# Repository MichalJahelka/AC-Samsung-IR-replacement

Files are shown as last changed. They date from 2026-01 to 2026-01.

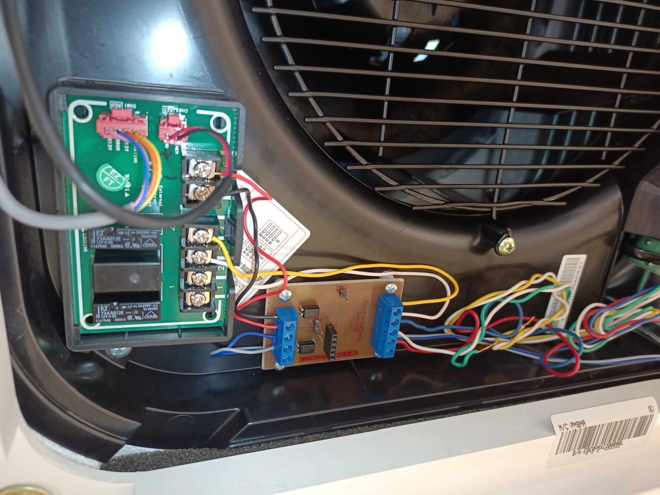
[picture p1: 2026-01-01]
Doc/Mount.jpg

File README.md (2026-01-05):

Wire replacement for SAMCUNG AC Remote Controller AR-EC03E/EH03E/EC03M/EH03M
IR protocol decoding, creating end sending example
IR protocol enconding for smart house realization

No protocol found for Samsung air condition IR control, so I had to catch communication with IR receiver (38 kHz) and decode it with MCU. I did not gues all bits, but the biggest part of protocol was decoded. For decoding is used PIC18F47K40, sends data throug serial line to terminal for display at PC. Program IRprotokolSamsungAC.X is written in MPLAB X, uses free compiler, has CZECH comments (so translator can be handy).
IRprotokolSamsungAC.X can decode protocols and after uncomment
//TransmittPacket(Paket,Delka);
//while(1);
can emulate one time data sending.
I tested it with IR LED, so pin with 38 kHz modulation is there too.

At second part KlimatizaceSamsung.X is practical usage. It uses iDum protocol for communication with control unit, data are passed to CreatePaket function and then created packet is send to output. It does not using IR LED, it connects throug optocoupler to IR receiver at AC unit, so modulation is not needed. Practilal realisation has schematic and PCB.

There is no problem to use it in another own device. Important is creating packet and sending it:
When data arrives:
if(Zprava.Data.Obsah.ZArray.Data[0]==rksCommand)
{
  Opt=(TOptions *)&Zprava.Data.Obsah.ZArray.Data[4];
  Swing=(TSwing *)&Zprava.Data.Obsah.ZArray.Data[6];
  i=CreatePaket(SamsungPaket,Zprava.Data.Obsah.ZArray.Data[1],    // Mode
                             Zprava.Data.Obsah.ZArray.Data[2],    // Temperature
                             Zprava.Data.Obsah.ZArray.Data[3],    // Fan
                             *Opt,                                // Options
                             *Swing,                              // Swing
                             Zprava.Data.Obsah.ZArray.Data[7],    // Zone
                             Zprava.Data.Obsah.ZArray.Data[8]);   // Direction
  VysliAccept();
  TransmittPacket(SamsungPaket,i);
  break;
}

And sending is automatic with TMR5 interrupt:
PIE4=0b00010011;      // TMR5IE,TMR2IE,TMR1IE
IPR4=0b00010001;      // TMR5 (Samsung transmitt), TMR1 (iDum) High priority

void __interrupt() Preruseni(void)
{
  iDumProcessIntr();
  TransmittBlockInterrupt(); // here is sending realized
}

CreatePaket, TransmittPacket and TransmittBlockInterrupt functions are parts of SamsungIR library.

Schematic is in KiCAD, extended documents are in CZECH language, use transaltor if you want.

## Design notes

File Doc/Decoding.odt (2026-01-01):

HDR0 CHK1 DI Q HDR1 ZoneCHK2 P SWING TUOL C YC Temp Fan+Mode RB pp

01000000 01001001 11110000 00000000 00000000 00000000 00001111 10000000 01000111 01111111 10001110 00000001 10000010 00001111 nic
01000000 01001001 11110000 00000000 00000000 00000000 00001111 10000000 01000011 01111111 11101110 00000001 10000010 00001111 turbo
01000000 01000001 11110000 00000000 00000000 00000100 00001111 10000000 01000111 01111111 10001110 00000001 10000010 00001111 quiet
01000000 01001001 11110000 00000000 00000000 00000000 00001111 10000000 01001011 01111111 10001110 10000001 10000010 00001111 cycle
01000000 01001001 11110000 00000000 00000000 00000000 00001111 10000000 01001011 01111111 10001110 00000001 10000010 00101111 beep
01000000 01000001 11110000 00000000 00000000 00000000 00001111 10000000 01001111 01111111 10000110 00000001 10000010 00001111 lightn
01000000 01001001 11110000 00000000 00000000 00000000 00001111 10000000 01000011 01111111 10001111 01000001 10000010 00001111 clean
01000000 01001001 11110000 00000000 00000000 00000000 00001111 10000000 01001011 01111111 10001110 00000001 10000010 01001111 reset
01000000 01000001 11110000 00001000 00000000 00000000 00001111 10000000 01000111 01111111 10001110 00000001 10000010 00001111 indirect
01000000 01000001 11110000 00000100 00000000 00000000 00001111 10000000 01000111 01111111 10001110 00000001 10000010 00001111 direct

01000000 01001110 11110000 00001000 00000000 00000100 00001111 10000000 01001011 01111111 10001110 00000001 10000010 00001111 Q+indir

01000000 01001110 11110000 00000100 00000000 00000100 00001111 10000000 01000111 01111111 10001110 00000001 10000010 00001111 Q+direct

01000000 01000001 11110000 00001000 00000000 00000000 00001111 10000000 01000111 01111111 11101110 00000001 10000010 00001111 T+indir

01000000 01000001 11110000 00000100 00000000 00000000 00001111 10000000 01000111 01111111 11101110 00000001 10000010 00001111 T+direct

01000000 01001001 11110000 00000000 00000000 00000000 00001111 10000000 01000101 01111111 11101110 10000101 10000010 00001111 T+cycle

01000000 01001001 11110000 00000000 00000000 00000000 00001111 10000000 01001101 01111111 11101110 10000101 10000010 01001111 cycle+R

CHK se mění při temp i option, takže asi chechsum, ale pro skupinu HDR1

DI – direction 0 není, 1 direct, 2 indirect

Y – cycle

C – Clean

L - /Ligtning pokud je lightning, je 0

Q – Quiet

B – Beep

R – Reset

P – Pokud je příkaz vypnutí, musí být 1, jinak je 0

p – Pokud je příkaz vypnutí, musí být 0, jinak je 1

TUO – Turbo 110 / Long 011

Vypnutí

Block 1: Bits 56

40 4D F0 00 00 00 03 - D:1

Block 2: Bits 56

80 4B F0 00 00 00 00 - B:1

Block 3: Bits 56

80 40 FF 8E 01 82 03 - 0:1

Off

Teplota: 24 °C

Mód: Heat

Ventilátor: Fan 1

Zone 1

Swing OFF

Options

Zapnutí

Block 1: Bits 56

40 49 F0 00 00 00 0F - 9:1

Block 2: Bits 56

80 4B F0 00 00 00 00 - B:1

Block 3: Bits 56

80 47 7F 8E 01 82 0F - 7:1

On

Teplota: 24 °C

Mód: Heat

Ventilátor: Fan 1

Zone 1

Swing OFF

Options

MODE auto

Block 1: Bits 56

40 49 F0 00 00 00 0F - 9:1

Block 2: Bits 56

80 47 7F 8E 03 80 0F - 7:1

On

Teplota: 28 °C

Mód: Auto

Ventilátor: Fan 1

Zone 1

Swing OFF

Options

Vypnutí při AUTO:

Block 1: Bits 56

40 4D F0 00 00 00 03 - D:1

Block 2: Bits 56

80 4B F0 00 00 00 00 - B:1

Block 3: Bits 56

80 40 FF 8E 05 80 03 - 0:1

Off

Teplota: 26 °C

Mód: Auto

Ventilátor: Fan 1

Zone 1

Swing OFF

Options

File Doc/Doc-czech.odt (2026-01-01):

Řízení klimatizace Samsung

Klimatizace používá k řízení dálkové ovladače. Prvním úkolem bylo získat protokol. Bohužel protokol je proprietární a není na internetu jsem nenašel konkrétní řešení pro tuto jednotku. Cílem bylo postavit zařízení, které by do vstupu dálkového ovládání pouštělo stejný signál, jako by byl stisk na dálkovém ovladači. Dálkový ovladač AR-EH03E se liší od ostatních ovladačů nejen protokolem, ale i tím, že je stavový – tedy dálkový ovladač si uchovává stav a zobrazuje ho na displeji.

# Dekódování DO AR-EH03E

Osciloskopem jsem zjistil, že DO vysílá na 38 kHz. Použil jsem integrovaný přijímač SFH5110-38 pro dekódování a logický analyzátor. Výsledkem byla sekvence začínající krátkým pulsem, pak 18 ms nic a pak další puls 3ms. Pak pauza 9ms a pak data 7 bytů při kódování 0 krátký puls, 1 dlouhý puls. Na konci je ještě 1 bit navíc, ale s délkou nuly 3ms. Pak následuje další rámec s 3 ms pulsem. Zajímavé je, že bit navíc není u posledního rámce.

Rámec se začátkem

Vždy krátká jednička (500us) a krátká nula (500us) dává logickou nulu nebo krátká jednička (500us) a dlouhá nula (1500us) dává logickou jedničku.

Ukázka 0 – 1 – 0

Rámce mohou být 2 nebo 3. 3 se typicky používají pro zapnutí a vypnutí, kdežto 2 při změně, když je ovladač aktivní. Pro dekódování jsem výstup z IR přijímače zapojil na INT0 mikropočítače (Jednoduchý MCU, PIC18F47K40, zrovna byl k dispozici) a výstup UART převedl přes převodník UART-USB do počítače. MCU posílá textové řetězce dekódovaných dat, které jsem zobrazil v terminálu.

Pro začátek bylo potřeba určit rámce. Rámec 1 nese informaci o zapnutí/vypnutí a případně další rozšiřující informace. Pak následuje rámec 2, který je přítomen jen při zapnutí a vypnutí a dálkový ovladač zde neposílá žádné užitečné informace (ať je nastavení jakékoliv, vždy je stejný). Poté následuje rámec 3, který nese informaci o nastavené teplotě.

HDR1 CHK1 DI Q

01000000 01001001 11110000 00000000 00000000 00000000 00001111

Příklad rámce 1

HDR3 ZoneCHK2 P SWING TULL C YC Temp Fan+Mode RB pp

10000000 01000111 01111111 10001110 00000001 10000010 00001111

Příklad rámce 3

CHK se mění při temp i option, takže checksum, ale jen pro daný rámec

DI – direction 0 není, 1 direct, 2 indirect

Y – cycle

C – Clean

L - /Ligtning pokud je lightning, je 0

Q – Quiet

B – Beep

R – Reset

P – Pokud je příkaz vypnutí, musí být 1, jinak je 0

p – Pokud je příkaz vypnutí, musí být 0, jinak je 1

TUL – Turbo 110 / Long 011

Parametry jsem určil experimentálně měřením. Například teplota je nestandardně kódovaná podle tabulky:

const uint8_t samsung_temp_table[15] = {

0x00, // 16 °C

0x08, // 17 °C

0x04, // 18 °C

0x0C, // 19 °C

0x02, // 20 °C

0x0A, // 21 °C

0x06, // 22 °C

0x0E, // 23 °C

0x01, // 24 °C

0x09, // 25 °C

0x05, // 26 °C

0x0D, // 27 °C

0x03, // 28 °C

0x0B, // 29 °C

0x07 // 30 °C

};

Nejsložitější bylo zjistit kontrolní součet. Ten počítá počet jedniček, nezapočítává vyšší nibble bytu 2 a používá nestandardní kódování, naštěstí obdobné pro počítání teploty.

const uint8_t Check_LUT[16] =

{

0xF,0x7,0xB,0x3,0xD,0x5,0x9,0x1,0xE,0x6,0xA,0x2,0xC,0x4,0x8,0x0

};

uint8_t SpocitejPocetJednicekB(uint8_t Cislo)

{

uint8_t Res=0;

while(Cislo)

{

if(Cislo & 0x01) Res++;

Cislo>>=1;

}

return Res;

}

// Vypočítá 4bitový CHK pro blok (stejné počítání jako při dekódování)

uint8_t Compute_Checksum(const uint8_t *b)

{

uint8_t k = 0;

k += SpocitejPocetJednicekB(b[0]);

k += SpocitejPocetJednicekB(b[1] & 0xF0); // horní nibble

k += SpocitejPocetJednicekB(b[2] & 0x0F); // dolní nibble

k += SpocitejPocetJednicekB(b[3]);

k += SpocitejPocetJednicekB(b[4]);

k += SpocitejPocetJednicekB(b[5]);

k += SpocitejPocetJednicekB(b[6]);

return Check_LUT[k & 0x0F];

}

Takže pak jsem stanovil struktury pro práci s daty:

typedef union {

uint8_t raw[7];

struct {

uint8_t hdr; // 0x40 = Block 1

uint8_t CHK:4; // Checksum

uint8_t unused1:4; // Musí být 0b0100

uint8_t unused2; // Musí být 0xF0

uint8_t unused3:2; // Musí být 0b00

uint8_t Direction:2; // Určuje směr 00 - žádný, 01 - direct, 10 - indirect

uint8_t unused4:4; // Musí být 0b0000

uint8_t unused5; // Musí být 00

uint8_t unused6:2; // Musí být 0b00

uint8_t Quiet:1; // Aktivní Quiet

uint8_t unused7:5; // Musí být 0b00000

uint8_t pwr; // Je buďto 0x0F pro zapnutí nebo 0x03 pro vypnutí

} data;

} SamsungAcBlock1_t;

typedef union {

uint8_t raw[7];

struct {

uint8_t hdr; // 0x80 = Block 2

uint8_t CHK:4; // Checksum

uint8_t unused1:4; // Musí být 0b0100

uint8_t unused2; // Musí být 0xF0

uint8_t unused3; // Musí být 0x00

uint8_t unused4; // Musí být 0x00

uint8_t unused5; // Musí být 0x00

uint8_t unused6; // Musí být 0x00 - tím odlišíme od bloku 3

} bits;

} SamsungAcBlock2_t;

typedef union {

uint8_t raw[7]; // 7 bajtů bloku 3

struct {

uint8_t block_id; // 0x80 = Block3

uint8_t Zone_CHK; // Byte1 – kód pro zónu + chcecksum

uint8_t Swing; // Byte2 – swing kód (0x7F, 0x75, 0x73, 0xF5…)

uint8_t Clean1:1; // Příkaz Clean

uint8_t unused1:2;

uint8_t nLightning:1; // Příkaz Lightning, normálně 1, když je lightning je 0

uint8_t Turbo:3; // Když je Turbo je 0b110

uint8_t unused3:1;

uint8_t temp:4; // Kód teploty (dekóduje se tabulkou)

uint8_t unused4:2;

uint8_t Clean2:1; // Příkaz Clean

uint8_t Cycle:1; // Aktivní Cycle

uint8_t modefan; // Byte5 – mód + nastavení ventilátoru

uint8_t unused5:5; // Má být vždy 0b01111

uint8_t Beep:1; // Příkaz Beep

uint8_t Reset:1; // Příkaz Reset

uint8_t unused6:1; // Má být vždy 0

} data;

} SamsungAcBlock3_t;

Po doplnění funkcí pro dekódování parametrů a jejich zobrazení, mi už MCU nejen vypisuje obsah rámců, ale počítá i kontrolní součet a vypisuje informace o stavu (co posílá DO) v čitelné podobě (tedy nastavenou teplotu, rychlost ventilátoru, mód, volby a swing).

# Emulace dálkového ovladače

Když už jsem uměl dekódování, bylo možno sestavit i enkódování, tedy sestavení celého paketu. K tomu souží funkce CreatePaket, co vytvoří 14 nebo 21 bytů. Totiž při zapnutí a vypnutí se vysílá 3x7 bytů dat, v ostatních případech jen 2x7 bytů. CreatePaket sestaví paket a vrací délku dat.

Pro vysílání dat je použita funkce TransmittPacket, která sestaví okamžiky změny výstupu (časové sekvence). Poté nastaví výstup do nuly a o samotné vysílání se již stará přerušení od časovače. Tím je dosaženo přesných časů, které nejsou ovlivněny chodem programu. Funkce také neblokuje program, což je důležité pro sběrnici iDům.

Protože je výstup optočlenu napojen na SFH5110 v klimatizační jednotce, není nutno vytvářet modulovaný 38 kHz signál. Při testech v kontaktním poli jsem to sice zkoušel, ale dosah takto vyrobeného dálkového ovladače byl velmi slabý. Musel jsem přijít až 1,5 m ke klimatizaci, když to konečně začalo fungovat. V originálním ovladači asi LED opravdu přebuzují.

# Hardware

Hardware je poměrně jednoduchý. Aby se klimatizační jednotka neovlivňovala se systémem iDům, je použito výstupních optočlenů. Výhodou je také, že výstup optočlenu mohu napojit paralelně k SFH5110. Druhý optočlen jsem použil pro spínání ON/OFF. Klimatizace dále obsahuje relé, které je sepnuto, když je klimatizace zapnuta. To vyhodnocuji pomocí spínání napětí. Linka iDům je řešena standardně pro PIC18F27K40, tedy N-MOSFET a rezistor. Komparátor a referenční napětí jsou součástí MCU.

## iDům

Zmínil jsem se několikrát o sběrnici iDům. To je otevřená (open source) sběrnice, kterou jsem před 20 léty navrhnul pro chytré domácnosti. Cílem bylo, aby byly koncové jednotky (např. vypínače) co nejlevnější a byl umožněn režim spánku. Je určena do rodinných domů. Hardwarově se jedná o sběrnici s otevřeným kolektorem a pull-up rezistorem. Jediným problémem se ukázala kapacita sběrnice. Když to bylo v rodinném domku, tak to fungovalo výborně, ale když to bylo vymyšleno a obchoďáci se rozhodli to použít do několika propojených paneláků o 14 patrech, už začal být problém s nabíjením sběrnice. Proto jsem pull-up rezistor nahradil stavovým zdrojem proudu, který řeší právě to nabíjení sběrnice. Setkal jsem se i s rušením, kdy propojili několik vchodů přes půdu a vytvořili tak přijímací anténu pro GSM vysílač na protější střeše. To v praxi nevymyslíš. Po několik let jsem vylepšoval i protokol, který obsahuje budící sekvenci, protikolizní ochranu (zamezení kolizím) a odpovědi v náhodných časech pro vyhnutí se kolizím. S touto sběrnicí se lze setkat také v systémech domácích telefonů Czechphone.

# Klimatizační jednotka

Po rozebrání je zde konektor, kde jsou zapojeny:

Oranžová | Vypínač
Hnědá | Společná zem
Fialová | Zapnuto LED anoda
Modrá | Zapnuto LED katoda
Šedá | Klapka LED anoda
Zelená | Klapka LED katoda
Fialová | Časovač LED anoda
Zelená | Časovač LED katoda
Fialová | Větrák LED anoda
Žlutá | Větrák LED katoda
Šedá | Mřížka LED anoda
Modrá | Mřížka LED katoda
Černá | +
Červená | Infra čidlo

Zatím máme bezpotenciálový spínač (s relátkem) mezi vypínač a společnou zem. Dále sledujeme svit Zapnuto LED přes optočlen. To chceme nahradit simulací dálkového ovládání na místo Infra čidla. Čidlo je klasické SFH5110, takže můžeme zapojit optočlen mezi infra čidlo a zem. Sledování a zapínání je vhodné mít také, proto je hardware navržen tak že i tyto původní funkce podporuje.

Dále je zde konektor pro napojení dálkového ovládání. To umožňuje připojit vypínač pro ON/OFF a obsahuje taky relé pro řízení stavu. A ještě jedno relé neznámého účelu.

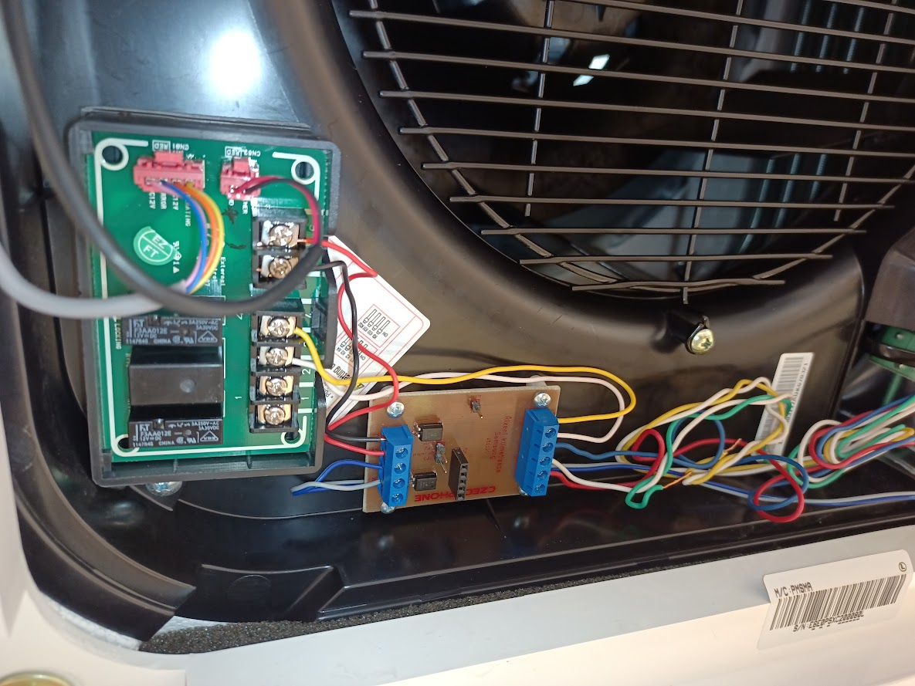
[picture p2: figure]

Vývody na rozšiřující desce 6 (+) a 5 (-) jsou pro připojení bezpotenciálového spínače dálkového zapnutí/vypnutí. K sepnutí postačí i optočlen. Vývody 4 a 5 jsou napojeny na kontakty relé, které je sepnuto, když je klimatizace zapnuta. Vývody 1 a 2 jsou připojeny k relé, o kterém nevím, kdy je sepnuto.

K rozhraní tedy připojuji 6 na S+, 5 na S-, a 4 a 5 na vývody Act. Z infračerveného rozhraní vedu vodiče out na IR+ a GND na IR-. Vše je tady galvanicky odděleno (pomocí optočlenů rozhraní nebo vnitřního relé klimatizace).

Aby bylo co nejméně práce v racku, připojil jsem + červená, - modrá a D bílá (kroucená se zelenou). Pokud bychom nenašli správnou bílou, je ji třeba před připojením rozhraní identifikovat. Bude na ni +5 V.

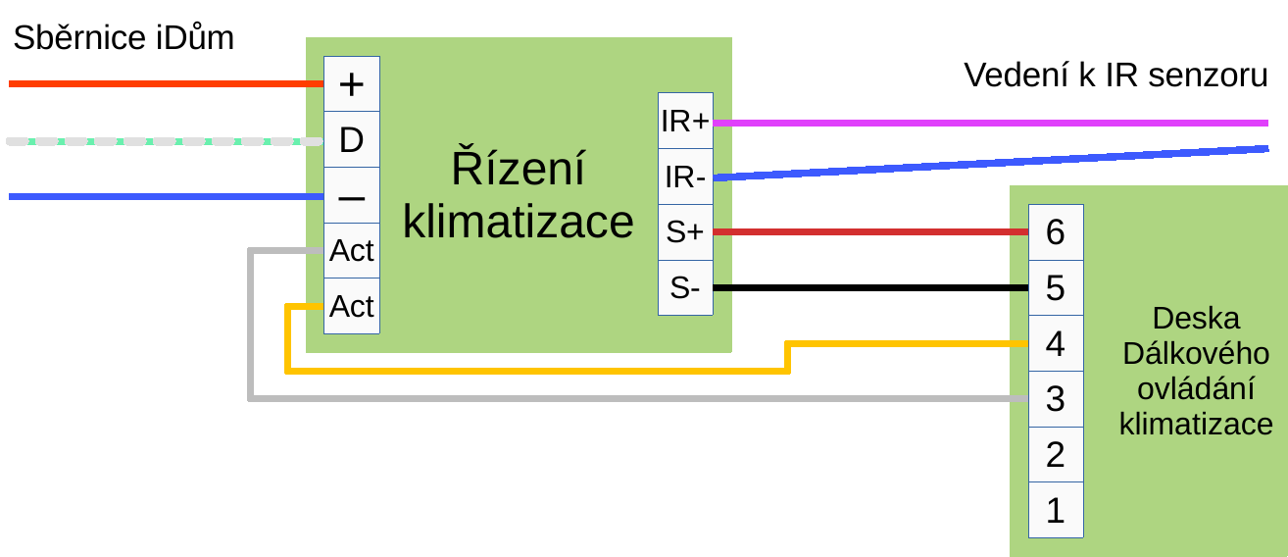
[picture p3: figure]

V rozvaděči je pak připojení co nejkratší, protože červená, modrá a bílá jsou napojeny na +, - a D linky iDům.

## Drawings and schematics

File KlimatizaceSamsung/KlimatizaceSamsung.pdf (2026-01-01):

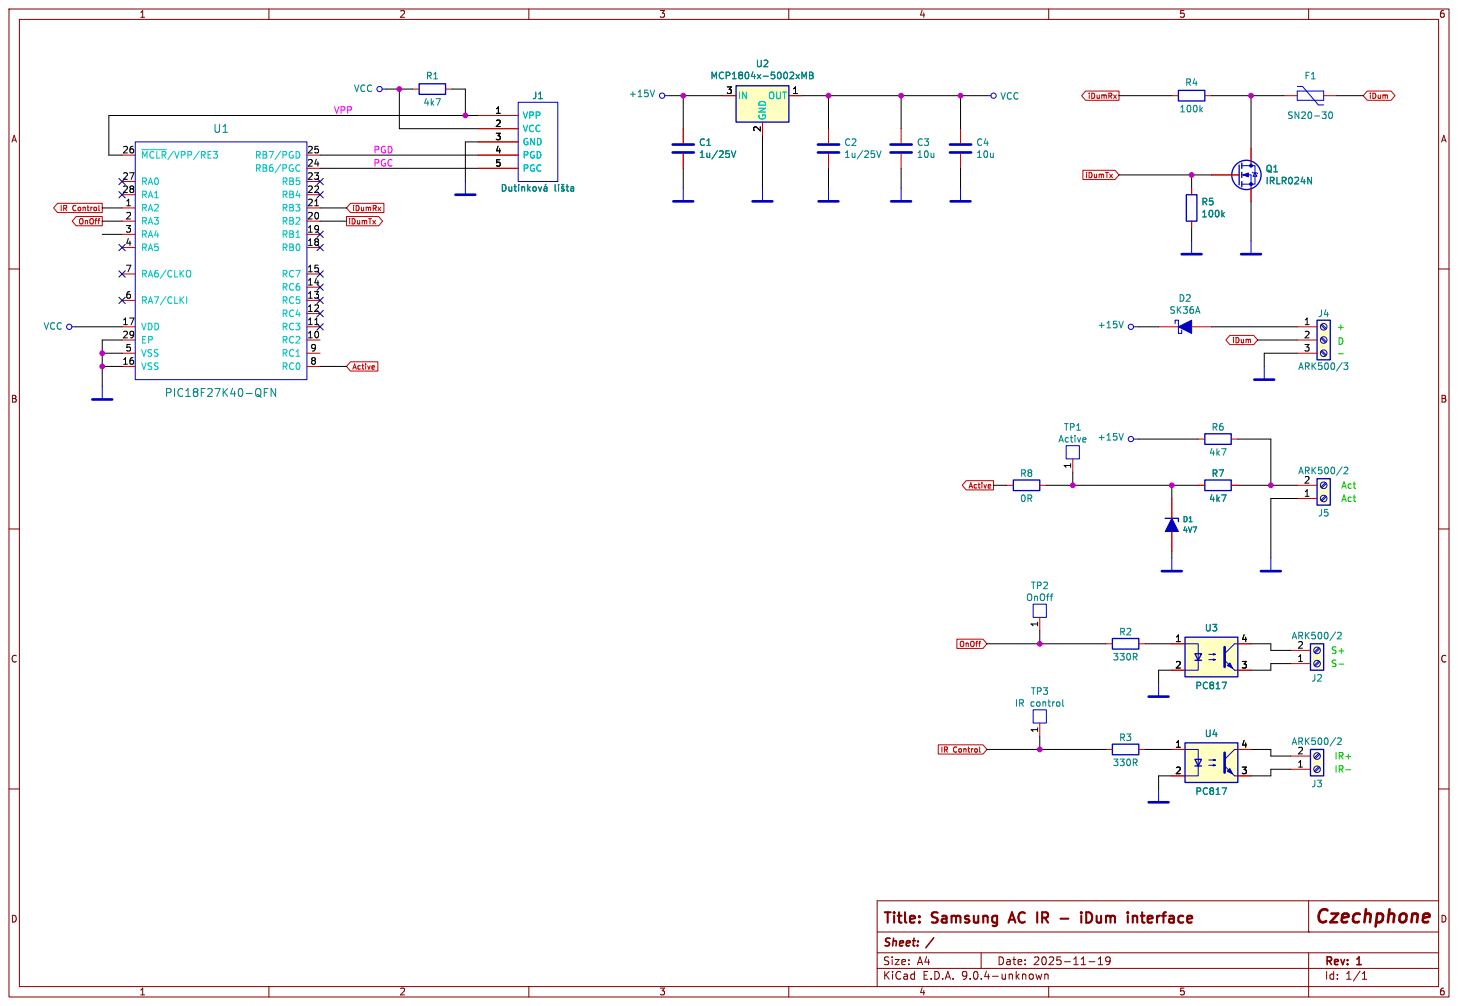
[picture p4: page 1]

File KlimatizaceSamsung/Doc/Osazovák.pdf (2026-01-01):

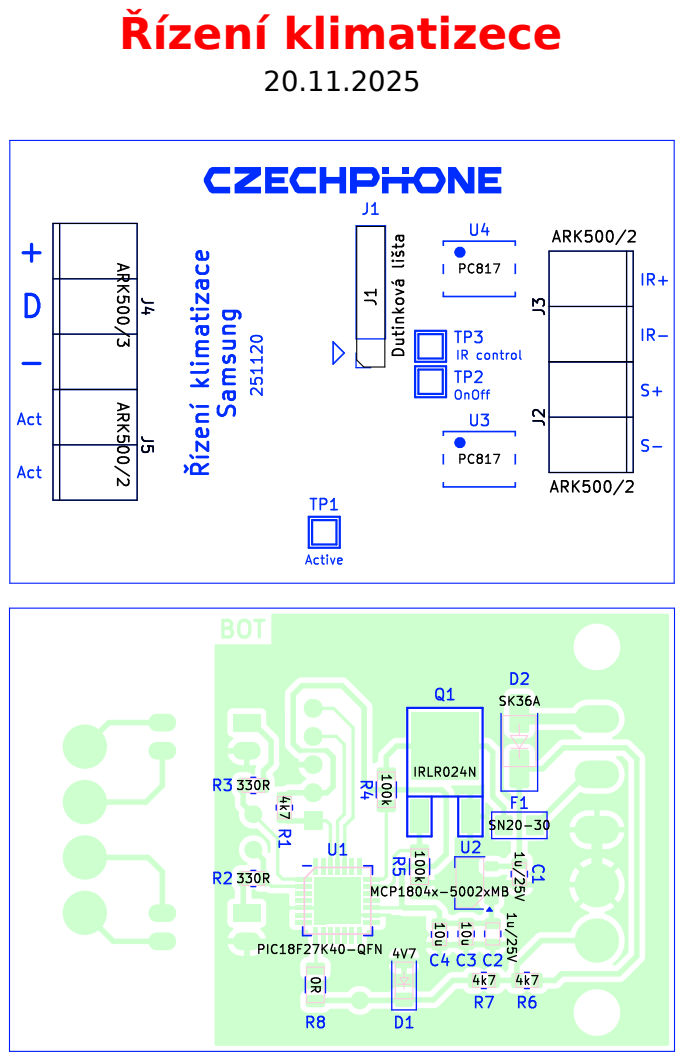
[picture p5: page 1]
Řízení klimatizece

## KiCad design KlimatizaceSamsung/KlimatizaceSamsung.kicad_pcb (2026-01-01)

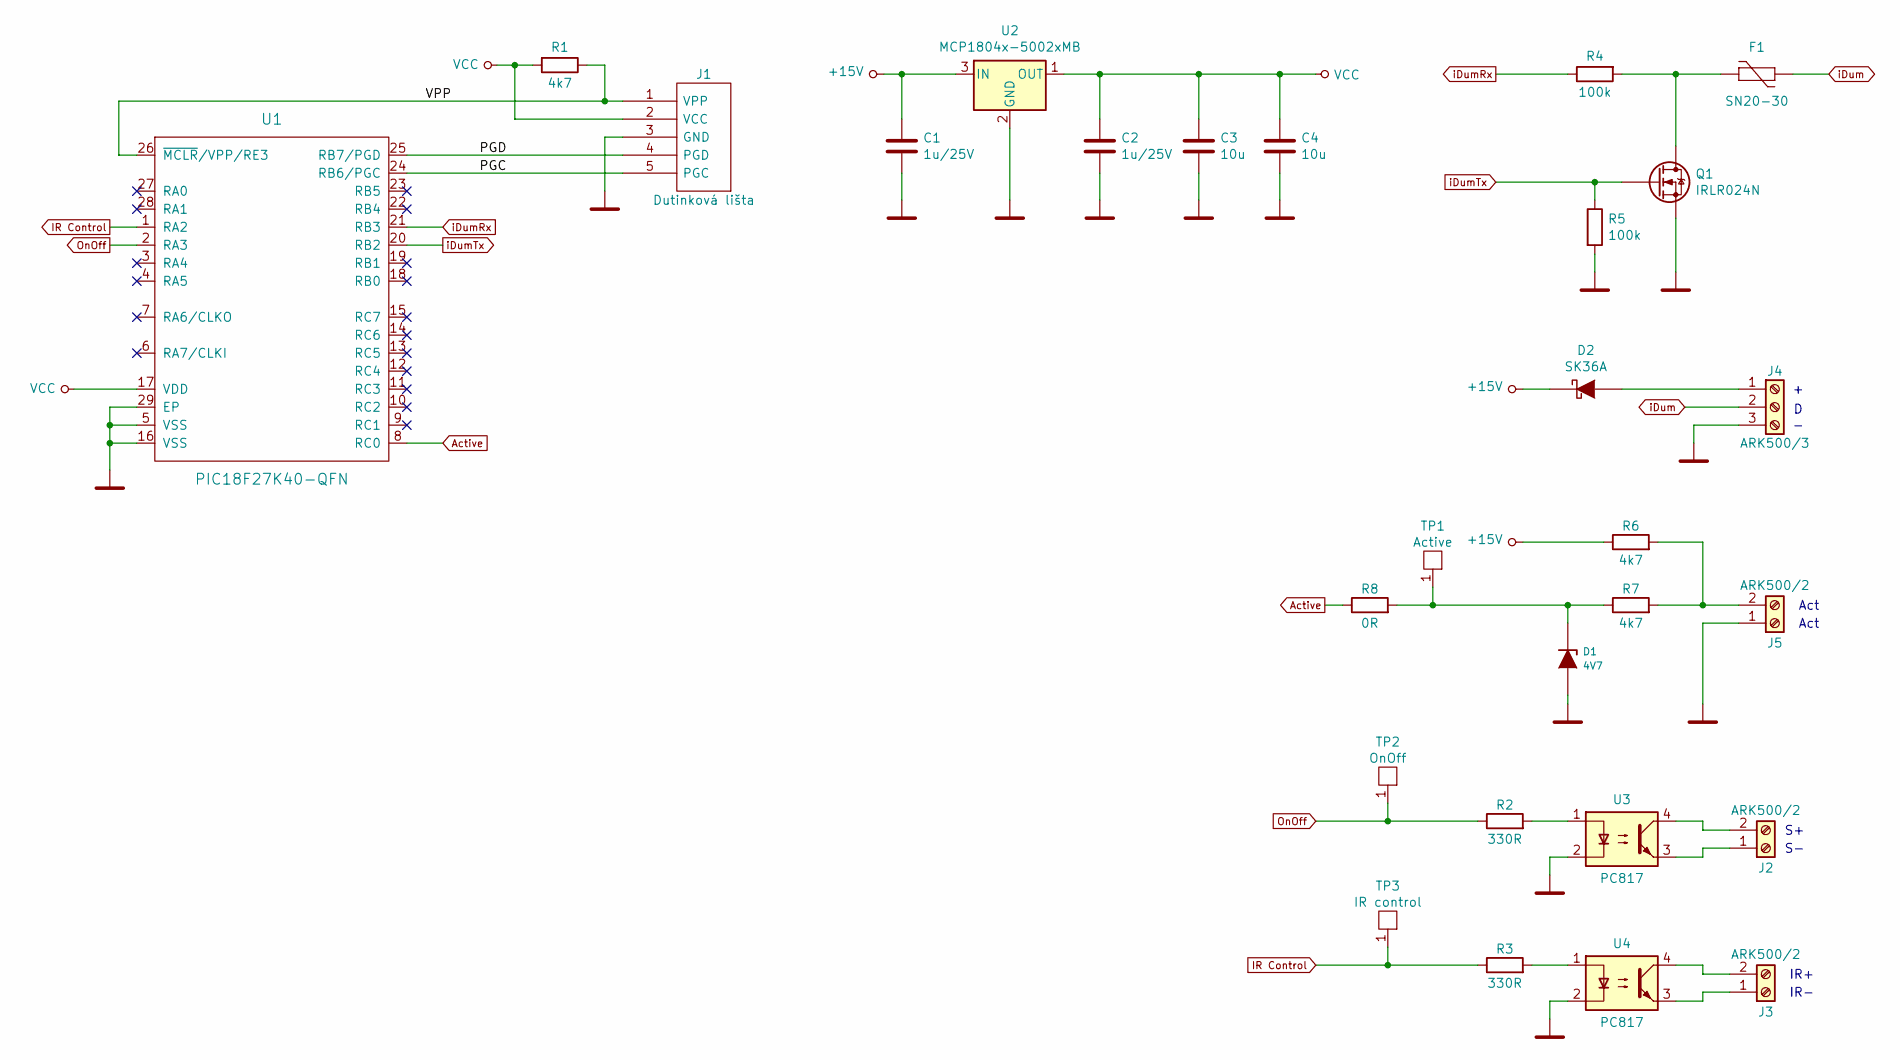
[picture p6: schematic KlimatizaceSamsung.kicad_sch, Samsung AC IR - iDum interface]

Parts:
C1, C2: 1u/25V; C_0805_2012Metric
C3, C4: 10u; C_0805_2012Metric
D1: 4V7; D_MiniMELF
D2: SK36A; D_SMA_Handsoldering
F1: SN20-30; PTC_SMD1206
J1: Dutinková lišta; PinSocket_1x05_P2.54mm_Vertical
J2, J3, J5: ARK500/2; DG301-5.0-2-LargePads
J4: ARK500/3; DG301-5.0-3-LargePads
Q1: IRLR024N; DPAKGDS
R1, R6, R7: 4k7; R_0805_2012Metric
R2, R3: 330R; R_0805_2012Metric
R4, R5: 100k; R_0805_2012Metric
R8: 0R; R_0805_2012Metric
TP1: Active; TP2
TP2: OnOff; TP2
TP3: IR control; TP2
U1: PIC18F27K40-QFN; QFN-PIC18F27K40
U2: MCP1804x-5002xMB; SOT-89-3
U3, U4: PC817

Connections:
+15V: C1.1, D2.1 (K), R6.1, U2.3 (IN)
/PGC: J1.5 (PGC), U1.24 (RB6/PGC)
/PGD: J1.4 (PGD), U1.25 (RB7/PGD)
/VPP: J1.1 (VPP), R1.1, U1.26 (~MCLR/VPP/RE3)
Active: R8.1, U1.8 (RC0)
GND: C1.2, C2.2, C3.2, C4.2, D1.2, J1.3 (GND), J4.3, J5.1, Q1.S, R5.2, U1.5 (VSS), U1.16 (VSS), U1.29 (EP), U2.2 (GND), U3.2, U4.2
IR Control: R3.1, TP3.1 (&1), U1.1 (RA2)
unnamed: D2.2 (A), J4.1
unnamed: F1.2, Q1.D, R4.2
unnamed: J2.1, U3.3
unnamed: J2.2, U3.4
unnamed: J3.1, U4.3
unnamed: J3.2, U4.4
unnamed: J5.2, R6.2, R7.2
unnamed: R2.2, U3.1
unnamed: R3.2, U4.1
unnamed: D1.1, R7.1, R8.2, TP1.1 (&1)
OnOff: R2.1, TP2.1 (&1), U1.2 (RA3)
VCC: C2.1, C3.1, C4.1, J1.2 (VCC), R1.2, U1.17 (VDD), U2.1 (OUT)
iDum: F1.1, J4.2
iDumRx: R4.1, U1.21 (RB3)
iDumTx: Q1.G, R5.1, U1.20 (RB2)

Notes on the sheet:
IR-
IR+
Act

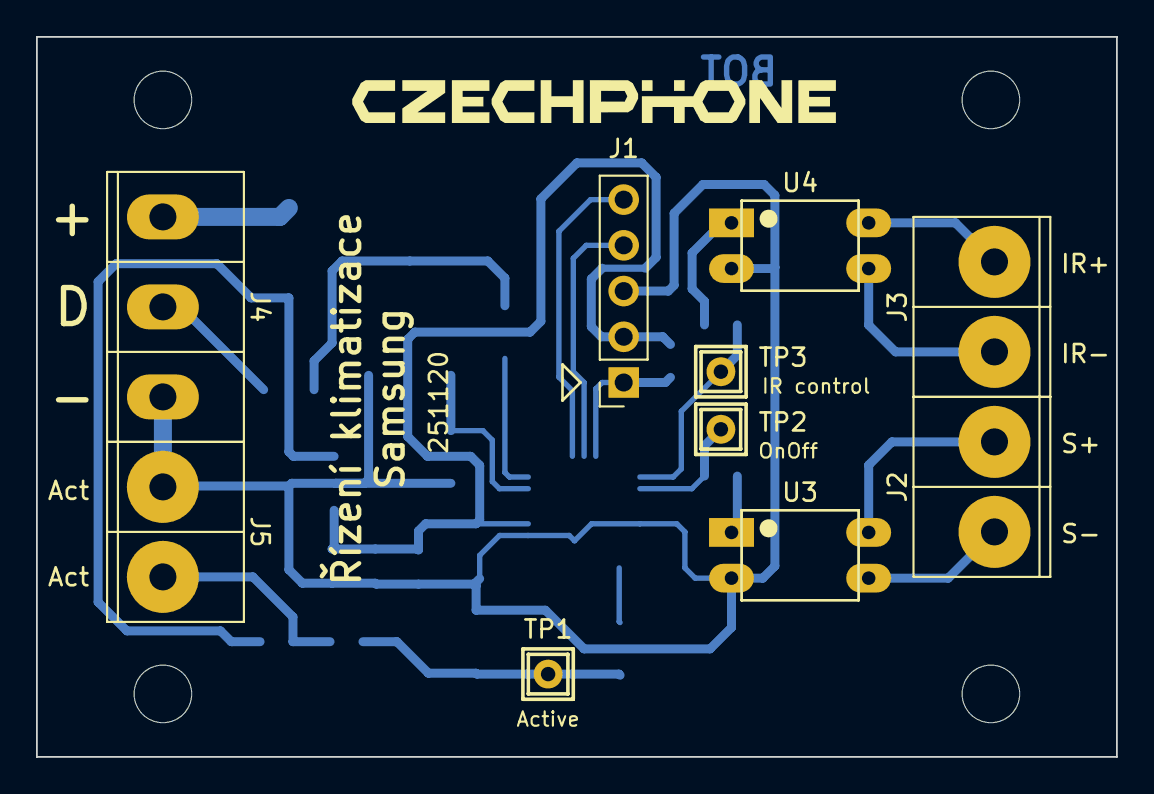
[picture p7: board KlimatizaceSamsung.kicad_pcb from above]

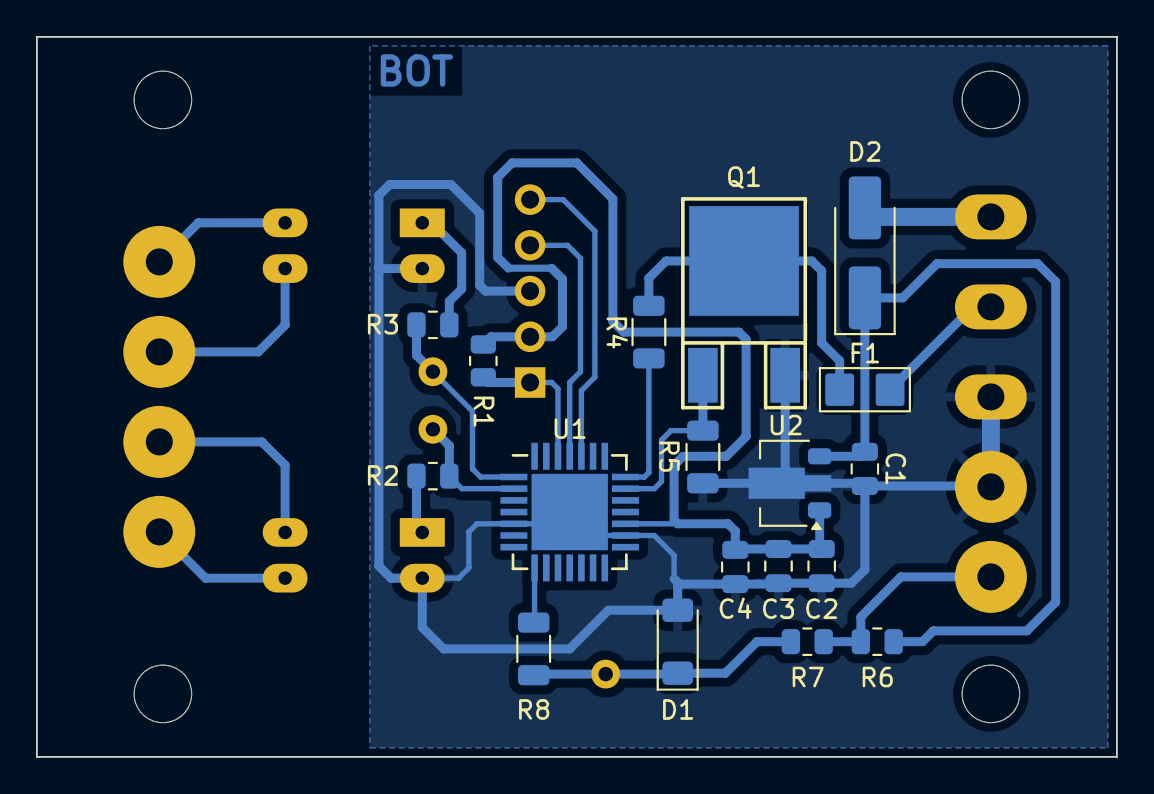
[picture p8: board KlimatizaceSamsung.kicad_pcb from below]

Board: 2 copper layers, 60.0 x 40.0 mm, 31 parts (18 on the bottom side), 22 nets.

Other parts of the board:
Dira3mmNTPH, Dira3mmNTPH#2, Dira3mmNTPH#3: Val**; Dira3,2mmNTPH

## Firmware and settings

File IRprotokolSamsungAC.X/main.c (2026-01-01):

#include <xc.h>
#include <stdint.h>
#include <stdbool.h>
#include <stdio.h>
#include <string.h>

// CONFIG1L
#pragma config FEXTOSC = OFF    // External Oscillator mode Selection bits (Oscillator not enabled)
#pragma config RSTOSC = HFINTOSC_1MHZ// Power-up default value for COSC bits (HFINTOSC with HFFRQ = 4 MHz and CDIV = 4:1)

// CONFIG1H
#pragma config CLKOUTEN = OFF   // Clock Out Enable bit (CLKOUT function is disabled)
#pragma config CSWEN = ON       // Clock Switch Enable bit (Writing to NOSC and NDIV is allowed)
#pragma config FCMEN = OFF      // Fail-Safe Clock Monitor Enable bit (Fail-Safe Clock Monitor disabled)

// CONFIG2L
#pragma config MCLRE = EXTMCLR  // Master Clear Enable bit (If LVP = 0, MCLR pin is MCLR; If LVP = 1, RE3 pin function is MCLR )
#pragma config PWRTE = OFF      // Power-up Timer Enable bit (Power up timer disabled)
#pragma config LPBOREN = OFF    // Low-power BOR enable bit (ULPBOR disabled)
#pragma config BOREN = SBORDIS  // Brown-out Reset Enable bits (Brown-out Reset enabled , SBOREN bit is ignored)

// CONFIG2H
#pragma config BORV = VBOR_2P45 // Brown Out Reset Voltage selection bits (Brown-out Reset Voltage (VBOR) set to 2.45V)
#pragma config ZCD = OFF        // ZCD Disable bit (ZCD disabled. ZCD can be enabled by setting the ZCDSEN bit of ZCDCON)
#pragma config PPS1WAY = OFF    // PPSLOCK bit One-Way Set Enable bit (PPSLOCK bit can be set and cleared repeatedly (subject to the unlock sequence))
#pragma config STVREN = ON      // Stack Full/Underflow Reset Enable bit (Stack full/underflow will cause Reset)
#pragma config DEBUG = OFF      // Debugger Enable bit (Background debugger disabled)
#pragma config XINST = OFF      // Extended Instruction Set Enable bit (Extended Instruction Set and Indexed Addressing Mode disabled)

// CONFIG3L
#pragma config WDTCPS = WDTCPS_31// WDT Period Select bits (Divider ratio 1:65536; software control of WDTPS)
#pragma config WDTE = OFF       // WDT operating mode (WDT Disabled)

// CONFIG3H
#pragma config WDTCWS = WDTCWS_7// WDT Window Select bits (window always open (100%); software control; keyed access not required)
#pragma config WDTCCS = LFINTOSC// WDT input clock selector (WDT reference clock is the 31.0 kHz LFINTOSC)

// CONFIG4L
#pragma config WRT0 = OFF       // Write Protection Block 0 (Block 0 (000800-003FFFh) not write-protected)
#pragma config WRT1 = OFF       // Write Protection Block 1 (Block 1 (004000-007FFFh) not write-protected)
#pragma config WRT2 = OFF       // Write Protection Block 2 (Block 2 (008000-00BFFFh) not write-protected)
#pragma config WRT3 = OFF       // Write Protection Block 3 (Block 3 (00C000-00FFFFh) not write-protected)
#pragma config WRT4 = OFF       // Write Protection Block 3 (Block 4 (010000-013FFFh) not write-protected)
#pragma config WRT5 = OFF       // Write Protection Block 3 (Block 5 (014000-017FFFh) not write-protected)
#pragma config WRT6 = OFF       // Write Protection Block 3 (Block 6 (018000-01BFFFh) not write-protected)
#pragma config WRT7 = OFF       // Write Protection Block 3 (Block 7 (01C000-01FFFFh) not write-protected)

// CONFIG4H
#pragma config WRTC = OFF       // Configuration Register Write Protection bit (Configuration registers (300000-30000Bh) not write-protected)
#pragma config WRTB = OFF       // Boot Block Write Protection bit (Boot Block (000000-0007FFh) not write-protected)
#pragma config WRTD = OFF       // Data EEPROM Write Protection bit (Data EEPROM not write-protected)
#pragma config SCANE = OFF      // Scanner Enable bit (Scanner module is NOT available for use, SCANMD bit is ignored)
#pragma config LVP = ON         // Low Voltage Programming Enable bit (Low voltage programming enabled. MCLR/VPP pin function is MCLR. MCLRE configuration bit is ignored)

// CONFIG5L
#pragma config CP = OFF         // UserNVM Program Memory Code Protection bit (UserNVM code protection disabled)
#pragma config CPD = OFF        // DataNVM Memory Code Protection bit (DataNVM code protection disabled)

// CONFIG5H

// CONFIG6L
#pragma config EBTR0 = OFF      // Table Read Protection Block 0 (Block 0 (000800-003FFFh) not protected from table reads executed in other blocks)
#pragma config EBTR1 = OFF      // Table Read Protection Block 1 (Block 1 (004000-007FFFh) not protected from table reads executed in other blocks)
#pragma config EBTR2 = OFF      // Table Read Protection Block 2 (Block 2 (008000-00BFFFh) not protected from table reads executed in other blocks)
#pragma config EBTR3 = OFF      // Table Read Protection Block 3 (Block 3 (00C000-00FFFFh) not protected from table reads executed in other blocks)
#pragma config EBTR4 = OFF      // Table Read Protection Block 4 (Block 4 (010000-013FFFh) not protected from table reads executed in other blocks)
#pragma config EBTR5 = OFF      // Table Read Protection Block 5 (Block 5 (014000-017FFFh) not protected from table reads executed in other blocks)
#pragma config EBTR6 = OFF      // Table Read Protection Block 6 (Block 6 (018000-01BFFFh) not protected from table reads executed in other blocks)
#pragma config EBTR7 = OFF      // Table Read Protection Block 7 (Block 7 (01C000-01FFFFh) not protected from table reads executed in other blocks)

// CONFIG6H
#pragma config EBTRB = OFF      // Boot Block Table Read Protection bit (Boot Block (000000-0007FFh) not protected from table reads executed in other blocks)

// #pragma config statements should precede project file includes.
// Use project enums instead of #define for ON and OFF.

#define _XTAL_FREQ      16000000UL

// === Parametry ===
#define MAX_SAMPLES     512   // musí být dost velké na celý rámec

#define MAX_BLOCKS      3
#define BITS_PER_BLOCK  56


#define VystupDO        LATAbits.LA3
#define VystupTest      LATAbits.LA2
#define Activate_TX()   { VystupDO=1;VystupTest=0; }
#define Deactivate_TX() { VystupDO=0;VystupTest=1; }

const uint8_t samsung_temp_table[15] = {
    0x00, // 16 °C
    0x08, // 17 °C
    0x04, // 18 °C
    0x0C, // 19 °C
    0x02, // 20 °C
    0x0A, // 21 °C
    0x06, // 22 °C
    0x0E, // 23 °C
    0x01, // 24 °C
    0x09, // 25 °C
    0x05, // 26 °C
    0x0D, // 27 °C
    0x03, // 28 °C
    0x0B, // 29 °C
    0x07  // 30 °C
};

const uint8_t Check_LUT[16] =
{
  0xF,0x7,0xB,0x3,0xD,0x5,0x9,0x1,0xE,0x6,0xA,0x2,0xC,0x4,0x8,0x0
};

/*
 * Bloky
 * Blok1 - Zapnutí/Vypnutí
 * Blok2 - Doplňkové informace, nemusí být, používá se jen při zapnutí a vypnutí
 * Blok3 - Data
 */

typedef union {
    uint8_t raw[7];
    struct {
        uint8_t hdr;          // 0x40 = Block 1
        uint8_t CHK:4;        // Checksum
        uint8_t unused1:4;    // Musí být 0b0100
        uint8_t unused2;      // Musí být 0xF0
        uint8_t unused3:2;    // Musí být 0b00
        uint8_t Direction:2;  // Určuje směr 00 - žádný, 01 - direct, 10 - indirect
        uint8_t unused4:4;    // Musí být 0b0000
        uint8_t unused5;      // Musí být 00
        uint8_t unused6:2;    // Musí být 0b00
        uint8_t Quiet:1;      // Aktivní Quiet
        uint8_t unused7:5;    // Musí být 0b00000
        uint8_t pwr;          // Je buďto 0x0F pro zapnutí nebo 0x03 pro vypnutí
    } data;
} SamsungAcBlock1_t;

typedef union {
    uint8_t raw[7];
    struct {
        uint8_t hdr;          // 0x80 = Block 2
        uint8_t CHK:4;        // Checksum
        uint8_t unused1:4;    // Musí být 0b0100
        uint8_t unused2;      // Musí být 0xF0
        uint8_t unused3;      // Musí být 0x00
        uint8_t unused4;      // Musí být 0x00
        uint8_t unused5;      // Musí být 0x00
        uint8_t unused6;      // Musí být 0x00 - tím odlišíme od bloku 3
    } bits;
} SamsungAcBlock2_t;

typedef union {
    uint8_t raw[7];  // 7 bajtů bloku 3

    struct {
        uint8_t block_id;     // 0x80 = Block3

        uint8_t Zone_CHK;     // Byte1 – kód pro zónu + chcecksum

        uint8_t Swing;        // Byte2 – detailní swing kód (0x7F, 0x75, 0x73, 0xF5…)

        uint8_t Clean1:1;     // Příkaz Clean
        uint8_t unused1:2;
        uint8_t nLightning:1; // Příkaz Lightning, normálně 1, když je lightning je 0
        uint8_t Turbo:3;      // Když je Turbo je 0b110
        uint8_t unused3:1;

        uint8_t temp:4;       // Kód teploty (dekóduje se tabulkou)
        uint8_t unused4:2;
        uint8_t Clean2:1;     // Příkaz Clean
        uint8_t Cycle:1;      // Aktivní Cycle

        uint8_t modefan;      // Byte5 – mód + nastavení ventilátoru

        uint8_t unused5:5;    // Má být vždy 0b01111
        uint8_t Beep:1;       // Příkaz Beep
        uint8_t Reset:1;      // Příkaz Reset
        uint8_t unused6:1;    // Má být vždy 0
    } data;
} SamsungAcBlock3_t;

volatile uint16_t durations[MAX_SAMPLES];
volatile uint8_t  levels[MAX_SAMPLES];
volatile uint16_t count = 0;

volatile uint16_t last_time = 0;
volatile uint8_t last_level = 1; // klidová úroveň = 1

volatile bool NovaData=false;
volatile uint8_t Aktivita=0;


typedef struct {
    uint8_t b1;
    uint8_t b2;
} ZoneSwingCode_t;

// pořadí: [zone][swing]
//
// zone = 0 → Zone1
// zone = 1 → Zone2
// zone = 2 → Zone3
// zone = 3 → Zone4
// zone = 4 → Zone1234
//
// swing = 0 → None
// swing = 1 → Y
// swing = 2 → X
// swing = 3 → XY
//
const ZoneSwingCode_t zone_swing_table[5][4] = {
    // Zone 1 (0x4?)
    {
        {0x47, 0x7F}, // None
        {0x40, 0xF5}, // Y
        {0x4F, 0x7D}, // X
        {0x40, 0xF3}  // XY
    },
    // Zone 2 (0xC?)
    {
        {0xCB, 0x7F}, // None
        {0xCF, 0x75}, // Y
        {0xC7, 0x7D}, // X
        {0xCF, 0x73}  // XY
    },
    // Zone 3 (0x2?)
    {
        {0x27, 0x7F}, // None
        {0x20, 0xF5}, // Y
        {0x2F, 0x7D}, // X
        {0x20, 0xF3}  // XY
    },
    // Zone 4 (0xA?)
    {
        {0xAB, 0x7F}, // None
        {0xAF, 0x75}, // Y
        {0xA7, 0x7D}, // X
        {0xAF, 0x73}  // XY
    },
    // Zone 1234 (0x9?)
    {
        {0x9B, 0x7F}, // None
        {0x9F, 0x75}, // Y
        {0x97, 0x7D}, // X
        {0x9F, 0x73}  // XY
    }
};

typedef union
{
  struct
  {
    uint8_t On:1;
    uint8_t Off:1;
    uint8_t Turbo:1;
    uint8_t Quiet:1;
    uint8_t Long:1;
    uint8_t Cycle:1;
    uint8_t Beep:1;
    uint8_t Lightning:1;
    uint8_t Clean:1;  
    uint8_t Reset:1;
  } Data;
  uint16_t Value;
} TOptions;

typedef enum
{
  Dir_None,
  Dir_Direct,
  Dir_Indirect,
} TDirection;

typedef enum
{
  Zone_1,
  Zone_2,
  Zone_3,
  Zone_4,
  Zone_1234,
} TZone;

typedef struct
{
  uint8_t X:1;
  uint8_t Y:1;
} TSwing;

typedef enum
{
  Mode_Auto=0,
  Mode_Heat,
  Mode_Cool,
  Mode_Fan,
  Mode_Dry,
} TMode;

// === ISR ===
void __interrupt() ISR(void) {
    if (INT0IF) 
    {
        uint16_t now = TMR1;
        uint16_t dt = now - last_time;
        last_time = now;

        if (count < MAX_SAMPLES) {
            durations[count] = dt;
            levels[count] = !last_level;
            count++;
        }

        // přepnout hranu
        last_level = !last_level;
        INTCONbits.INT0EDG = last_level; // pokud teď 1, čekej sestup; pokud 0, čekej náběh

        INT0IF = 0;
        Aktivita=10;
        NovaData=true;
    }
}

// === UART ===
void UART_Init(void) {
    SP1BRG = 34; // 115200 Bd @ 16 MHz
    TX1STAbits.BRGH = 1;
    BAUD1CONbits.BRG16 = 1;

    RC1STAbits.SPEN = 1;
    TX1STAbits.TXEN = 1;
}

void UART_PutChar(char c) {
    while(!TX1STAbits.TRMT);
    TX1REG = c;
}

void UART_PutString(const char *s) {
    while(*s) UART_PutChar(*s++);
}

int decodeTemp(uint8_t code) {
    for (int t = 16; t <= 30; t++) {
        if (samsung_temp_table[t - 16] == (code & 0x0F))
            return t;
    }
    return -1; // chyba
}

const char* decode_zone(uint8_t b1, uint8_t b2) {
    // rozpoznání zóny
    switch(b1 & 0xF0) {
        case 0x40: return "Zone 1";
        case 0xC0: return "Zone 2";
        case 0x20: return "Zone 3";
        case 0xA0: return "Zone 4";
        case 0x90: return "Zone 1+2+3+4";
        default:   return "Unknown zone";
    }
}

const char* decode_swing(uint8_t b1, uint8_t b2) {
    if (b2 == 0x7F || b2 == 0xFF)  return "Swing OFF";
    if (b2 == 0xF5 || b2 == 0x75) return "Swing Y";
    if (b2 == 0x7D) return "Swing X";
    if (b2 == 0xF3 || b2 == 0x73) return "Swing XY";
    return "Unknown swing";
}

const char* decode_mode(uint8_t code)
{
    switch (code & 0x0F) 
    { 
        case 0b0000: return "Auto";
        case 0b0010: return "Heat";
        case 0b1000: return "Cool";
        case 0b1100: return "Fan";
        case 0b0100: return "Dry";
        default:    return "Unknown";
    }
}

const char* decode_fan(uint8_t code)
{
    switch (code >> 4) 
    {  
        case 0b1000: return "Fan 1";
        case 0b1010: return "Fan 2";
        case 0b1001: return "Fan 3";
        case 0b1101: return "Fan 4 (Turbo)";
        default:    return "Unknown";
    }
}

void decode_options(SamsungAcBlock1_t Samsung1, SamsungAcBlock3_t Samsung2, char* out, size_t outlen)
{ 
    strcpy(out, "Options: ");

    if(Samsung2.data.Turbo == 0b110) strcat(out, "Turbo, ");
    if(Samsung2.data.Turbo == 0b011) strcat(out, "Long, ");
    if(Samsung1.data.Quiet) strcat(out, "Quiet, ");
    if(Samsung2.data.Cycle) strcat(out, "Cycle, ");
    if(Samsung1.data.Direction == 0b01) strcat(out, "Direct, ");
    if(Samsung1.data.Direction == 0b10) strcat(out, "Indirect, ");
    if(Samsung2.data.Beep) strcat(out, "Beep, ");
    if(Samsung2.data.Reset) strcat(out, "Filter reset, ");
    if(Samsung2.data.Clean1 && Samsung2.data.Clean2) strcat(out, "Clean, ");
    if(!Samsung2.data.nLightning) strcat(out, "Lightning, ");

    // --- odstranit poslední čárku + mezeru ---
    size_t len = strlen(out);
    if (len > 2) 
    {
      out[len-2] = '\n';
      out[len-1] = 0;
    }
}

uint8_t SpocitejPocetJednicekB(uint8_t Cislo)
{
  uint8_t Res=0;
  
  while(Cislo)
  {
    if(Cislo & 0x01) Res++;
    Cislo>>=1;
  }
  return Res;
}

// Vypočítá 4bitový CHK pro blok (stejné počítání jako při dekódování)
uint8_t Compute_Checksum(const uint8_t *b)
{
    uint8_t k = 0;
    k += SpocitejPocetJednicekB(b[0]);
    k += SpocitejPocetJednicekB(b[1] & 0xF0);  // horní nibble
    k += SpocitejPocetJednicekB(b[2] & 0x0F);  // dolní nibble
    k += SpocitejPocetJednicekB(b[3]);
    k += SpocitejPocetJednicekB(b[4]);
    k += SpocitejPocetJednicekB(b[5]);
    k += SpocitejPocetJednicekB(b[6]);

    return Check_LUT[k & 0x0F];
}

// --- Příklad použití při generování rámce ---
void Update_Block_Checksum(uint8_t *b)
{
    uint8_t chk = Compute_Checksum(b);
    b[1] = (b[1] & 0xF0) | chk;  // přepiš spodní nibble
}

void decode_and_print(void) 
{
    uint8_t bitbuf[MAX_BLOCKS][BITS_PER_BLOCK/8+1] = {{0}};
    uint16_t bitcount[MAX_BLOCKS] = {0};
    uint8_t block_index = 0;
    bool in_data = false;
    uint16_t i;
    uint16_t dur;
    uint8_t lvl;
    char buf[128];
    SamsungAcBlock1_t Samsung1;
    SamsungAcBlock3_t Samsung3;
    uint8_t j,k;

    for (i=0; i+1<count && block_index < MAX_BLOCKS; i++) 
    {
        //sprintf(buf, "%04X", i);
        //UART_PutString(buf);
        dur = durations[i]/2;   // µs
        lvl  = levels[i];

        // --- čekáme na 3ms sync puls v log.1 ---
        if (lvl==0 && dur>2500 && dur<3500) 
        {
          if(in_data) block_index++;
          in_data = true;
          bitcount[block_index] = 0;
          memset(bitbuf[block_index], 0, sizeof(bitbuf[block_index]));
          continue;
        }
        
        if(!in_data) continue;

        // --- ignoruj cokoliv delší než 3ms ---
        if (dur > 3000) 
        {
          Nop();
          continue;
        }

        // --- dekódování bitů: mark + space ---
        if ((lvl==0)&&(dur>300)&&(dur<800))
        { // puls ~500 µs
            if ((i+1<count) && (levels[i+1]==1)) 
            {
                uint16_t space = durations[i+1]/2;

                if (space>300 && space<800) 
                {
                    // bit 0
                    bitbuf[block_index][bitcount[block_index]/8] <<= 1;
                    bitcount[block_index]++;
                } 
                else
                {
                    // bit 1
                    bitbuf[block_index][bitcount[block_index]/8] <<= 1;
                    bitbuf[block_index][bitcount[block_index]/8] |= 1;
                    bitcount[block_index]++;
                }
            }
        }

        // --- konec bloku ---
        if (bitcount[block_index] >= BITS_PER_BLOCK) 
        {
            block_index++;
            in_data = false;   // zpět k hledání syncu
        }
    }

    // --- výpis všech bloků ---
    for (uint8_t b=0; b<block_index; b++) 
    {
        sprintf(buf, "Block %u: Bits %u\r\n", b+1, bitcount[b]);
        
        UART_PutString(buf);

        //k=0;
        for (i=0; i<(bitcount[b]+7)/8; i++) 
        {
            sprintf(buf, "%02X ", bitbuf[b][i]);
            UART_PutString(buf);
            /*if(i==1) k+=SpocitejPocetJednicekB(bitbuf[b][i] & 0xF0);
               else if(i==2) k+=SpocitejPocetJednicekB(bitbuf[b][i] & 0x0F);
                        else k+=SpocitejPocetJednicekB(bitbuf[b][i]);*/
        }
        //sprintf(buf, "- %X:%i", Check_LUT[k&0x0F], Check_LUT[k&0x0F] == (bitbuf[b][1] & 0x0F));
        k=Compute_Checksum(bitbuf[b]);
        sprintf(buf, "- %X:%i", k, k == (bitbuf[b][1] & 0x0F));
        UART_PutString(buf);

        UART_PutString("\r\n");
    }
    
    memcpy(Samsung1.raw, bitbuf[0], 7);
    if(Samsung1.data.pwr==0x0F) UART_PutString("On\n");
                           else UART_PutString("Off\n");
    // Samsung2 nebudeme vůbec dekódovat
    if(bitbuf[1][6]==0x00) memcpy(Samsung3.raw, bitbuf[2], 7);
                      else memcpy(Samsung3.raw, bitbuf[1], 7);
    sprintf(buf,"Teplota: %u °C\n", decodeTemp(Samsung3.data.temp));
    UART_PutString(buf);
    sprintf(buf,"Mód: %s\n",decode_mode(Samsung3.data.modefan));
    UART_PutString(buf);
    sprintf(buf,"Ventilátor: %s\n", decode_fan(Samsung3.data.modefan));
    UART_PutString(buf);
    sprintf(buf,"%s\n",decode_zone(Samsung3.data.Zone_CHK,Samsung3.data.Swing));
    UART_PutString(buf);
    sprintf(buf,"%s\n",decode_swing(Samsung3.data.Zone_CHK,Samsung3.data.Swing));
    UART_PutString(buf);
    decode_options(Samsung1, Samsung3, buf, sizeof(buf));
    UART_PutString(buf);
}


// === Debug výpis surových dat ===
void debug_print_samples(void) {
    char buf[32];
    UART_PutString("Samples: ");
    for (uint16_t i=0; i<count; i++) {
        sprintf(buf, "%u:%u,", durations[i]/2, levels[i]); // převod na µs
        UART_PutString(buf);
    }
    UART_PutString("\r\n");
}

uint8_t EncodeZone(TZone Zone)
{
  switch(Zone)
  {
    case Zone_1:return 0x40;
    case Zone_2:return 0xC0;
    case Zone_3:return 0x20;
    case Zone_4:return 0xA0;
    case Zone_1234:return 0x90;
    default:return 0x00;
  }
  return 0x00;
}

uint8_t EncodeSwing(TSwing Swing)
{
  if((Swing.X)&&(!Swing.Y)) return 0x7D;
  if((!Swing.X)&&(Swing.Y)) return 0x75;
  if((Swing.X)&&(Swing.Y)) return 0x73;
  return 0x7F;
}

uint8_t EncodeTemp(uint8_t Temperature)
{
  if(Temperature<16) Temperature=16;
  if(Temperature>30) Temperature=30;
  Temperature-=16;
  return samsung_temp_table[Temperature];
}
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
void main(void) 
{
  uint8_t Paket[3*7];
  uint8_t Delka;
  TOptions Opt;
  TSwing Swing;

  // Oscilátor 16 MHz
  OSCCON1 = 0x60;
  OSCFRQ = 0x05;

  // PPS
  PPSLOCK = 0x55; PPSLOCK = 0xAA; PPSLOCKbits.PPSLOCKED = 0;
  RC6PPS = 0x09;    // TX -> RC6
  RX1PPS = 0x17;    // RX <- RC7 (není potřeba, ale pro jistotu)
  INT0PPS = 0x08;   // RB0 -> INT0
  RB3PPS = 0x05;    // CCP1 -> RB3
  RA0PPS = 0x15;    // DSM -> RA0
  MDSRCPPS = 0x03;  // RA3  -> MDSRC
  PPSLOCK = 0x55; PPSLOCK = 0xAA; PPSLOCKbits.PPSLOCKED = 1;
  
  TRISAbits.TRISA3=0;
  ANSELAbits.ANSELA3=0;
  LATAbits.LATA3=0;
  TRISAbits.TRISA2=0;
  ANSELAbits.ANSELA2=0;
  LATAbits.LATA2=1;
  TRISAbits.TRISA0=0;
  ANSELAbits.ANSELA0=0;
  LATAbits.LATA3=0;
  TRISBbits.TRISB3=0;
  ANSELBbits.ANSELB3=0;
  
  T3CON=0b00000101;             // Zapnout TMR3
  TMR3CLK=0b0001;               // Hodiny fosc (4 MHz)
  CCPTMRS=0b10101010;           // CCP bude používat TMR3, PWM - TMR4
  CCPR1=_XTAL_FREQ/4/38500/2;   // Nastavíme frekvenci na 38.5kHz
  CCP1CON=0b10000001;           // Enable, Compare mode, toggle output and clear TMR3
  
  MDCON0=0b10000000;            // Zapneme DSM
  MDCON1=0b00010001;            // Synchronně, pulsy budou neořezané a dokončené v celé délce
  MDCARH=0b00000100;            // Vstup modulace H je CCP1
  MDCARL=0b00000000;            // Není (výběr PPS, ale tam není nic)
  MDSRC=0b00000000;             // PIN vybraný MDSRCPPS
  
  
  __delay_ms(100);

  UART_Init();

  // Timer1 @ 2 MHz (0,5 µs/tick)
  T1CONbits.CKPS = 0b01; // 1:2
  T1CLK = 0x01;          // Fosc/4
  TMR1 = 0;
  T1CONbits.TMR1ON = 1;

  // INT0
  TRISBbits.TRISB0 = 1;
  ANSELBbits.ANSELB0 = 0;
  INTCONbits.INT0EDG = 0; // začneme sestupnou hranou
  last_level = 0;         // protože čekáme na sestup
  INT0IF = 0;
  INT0IE = 1;
  INTCONbits.GIE = 1;

  Opt.Value=0;
  Opt.Data.On=0;
  Opt.Data.Off=1;
  Swing.X=0;        // Není u této klimatizace funkční
  Swing.Y=0;
  //Delka=CreatePaket(Paket,Mode_Heat,24,3,Opt,Swing,Zone_1,Dir_None);
  Delka=CreatePaket(Paket,Mode_Fan,25,1,Opt,Swing,Zone_1,Dir_None);
  
  
  /*Delka=21;
  Paket[0]=0x40;
  Paket[1]=0x49;
  Paket[2]=0xF0;
  Paket[3]=0x00;
  Paket[4]=0x00;
  Paket[5]=0x00;
  Paket[6]=0x0F;
  
  Paket[7]=0x80;
  Paket[8]=0x4B;
  Paket[9]=0xF0;
  Paket[10]=0x00;
  Paket[11]=0x00;
  Paket[12]=0x00;
  Paket[13]=0x00;
  
  Paket[14]=0x80;
  Paket[15]=0x4B;
  Paket[16]=0x7F;
  Paket[17]=0x8E;
  Paket[18]=0x03;
  Paket[19]=0x82;
  Paket[20]=0x0F;*/
  
  //TransmittPacket(Paket,Delka);
  //while(1);
  
  UART_PutString("Samsung AC IR capture ready\r\n");

  while (1) 
  {
    __delay_ms(5);
    if((!Aktivita)&&(NovaData))
    {
      INT0IE = 0;
      //debug_print_samples(); // surový výpis
      decode_and_print();
      count = 0;
      NovaData=false;
      INT0IE = 1;
    }
    if(Aktivita) Aktivita--;
  }
}

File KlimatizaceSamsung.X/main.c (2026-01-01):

/*
 * Řízení klimatizace Samsung - simulace dálkovéhbo ovládání
 * Výstup je napojen přímo na čidlo, není nutný modulovaný signál
 * Kromě toho má obvod pro zjištění stavu a spínač
 */

#include <xc.h>
#include "mcc_generated_files/memory.h"
#include "Variables.h"
#include "iDum.h"
#include "../../Extended.h"
#include "SamsungIR.h"

void __interrupt() Preruseni(void)
{
  iDumProcessIntr();
  TransmittBlockInterrupt();
}

void __interrupt(low_priority) NizkePreruseni(void)
{
  // Systémový časovač 1 ms
  if(TMR2IF)
  {
    TMR2IF=0;
    ByloPreruseni2=1;
    
    if(CasZakmitu) CasZakmitu--;
    if(CasDelay) CasDelay--;
  }
  if(PIR0bits.IOCIF)
  {
    IOCCF=0;
    PIR0bits.IOCIF=0;
  }
}

void ZjistiVstupy()
{
  Vstup=0;
  if(!Active) Vstup|=0x01;
  if(Vstup!=StaryVstup)
  {
    BylaZmenaVstupu=1;
    StaryVstup=Vstup;
    CasZakmitu=DATAEE_ReadByte(EEPROM_CasZakmitu);
  }
}

void main(void)
{
  unsigned char i,j;
  TOptions *Opt;
  TSwing *Swing;
  
  // NOSC HFINTOSC; NDIV 1
  OSCCON1 = 0x60;
  // CSWHOLD may proceed; SOSCPWR Low power; 
  OSCCON3 = 0x00;
  // MFOEN disabled; LFOEN disabled; ADOEN disabled; SOSCEN disabled; EXTOEN disabled; HFOEN disabled; 
  OSCEN = 0x00;
  // HFFRQ 16MHz; 
  OSCFRQ = 0x05;
  // TUN 0; 
  OSCTUNE = 0x00;
  
  LATA=0b00000000;
  LATB=0b00000000;
  LATC=0b00000000;
  
  TRISA=0b00000000;
  TRISB=0b11001000;
  TRISC=0b00000001;
  
  ANSELA=0b00000000;
  ANSELB=0b00000000;
  ANSELC=0b00001000;  
  
  WPUA=0b00000000;
  WPUB=0b11000000;        // Pull-Up na ICSP
  WPUC=0b00000000;
  
  ODCONA = 0x00;
  ODCONB = 0x00;
  ODCONC = 0x00;
  
  IOCCP=0b00000001;
  IOCCN=0b00000001;
  
  // D/A převodník pro komparátor
  DAC1CON0=0b10000000;  // Zapnut, bez výstupu, AVDD a AVSS
  DAC1CON1=16;          // Polovina (2.5V)
  
  // Komparátor
  CM1CON0=0b11010000; // Zapnut, inverted, nemá hysterezi, async
  CM1CON1=0b00000000; // Nepovolit přerušení
  CM1NCH=0b000000010; // NCH = Cin2-
  CM1PCH=0b000000101; // PCH = DACOUT
  
  if(!PCON0bits.nPOR)
  {
    IDV_OK=0;
    IDV_Sent=0;
    IDV_Fail=0;
    IDV_Error=0;
    IDV_Conflict=0;
    IDV_Reset=0;
    PCON0bits.nPOR=1;
  }
  IDV_Reset++;
  
  ReloadEEPROM();
  
  CasZakmitu=0;
  
  GIE = 0;
  PPSLOCK = 0x55;
  PPSLOCK = 0xAA;
  PPSLOCKbits.PPSLOCKED = 0x00;         // unlock PPS
  
  RC7PPS = 0x0D;                        // C1OUT -> RC7
  RX1PPSbits.RXPPS=0b10111;             // RC7   -> RX1
  iDumTxIO();
    
  PPSLOCK = 0x55;
  PPSLOCK = 0xAA;
  PPSLOCKbits.PPSLOCKED = 0x01;         // lock PPS
  
  BAUDCON1=0b01010000;           // Tx inverted
  SPBRG1=CrystalFreq/16/19200-1;
  RCSTA1=0b00000000;             // Serial port disabled
  TXSTA1=0b00100110;             // TX enable, BRGH
  i=RC1REG;                      // Při povolení nastaveno přerušení; zrušit příznak
  
  TMR1=Cas1ms;
  T1GCON=0;
  TMR1CLK=0b00000001;           // fosc/4
  T1CON=0b00000001;             // Zapnout TMR1
  
  TMR2=0;
  T2HLT=0b00000000;             // Free running, software control
  T2CLKCON=0b00000001;          // fosc/4
  T2CON=0b11000000;             // Enable TMR2, prescaler 16, postscaler 1
  PR2=CrystalFreq/4/16/1/1000;  // 1 ms
  
  TMR3CLK=0b0100;               // LFINTOSC (pro náhodné číslo)
  T3CON=0b00000001;             // TMR3ON
  
  PIR0=0;
  PIR1=0;
  PIR3=0;
  PIR4=0;
  PIR5=0;
  PIR6=0;
  
  PIE0=0b00000000;
  PIE1=0b00000000;
  PIE2=0b00000001;      // Komparátor CMP1
  PIE3=0b00000000;
  PIE4=0b00010011;      // TMR5IE,TMR2IE,TMR1IE
  PIE5=0b00000000;
  PIE6=0b00000000;
  PIE7=0b00000000;
  
  IPR0=0b00000000;
  IPR1=0b00000000;
  IPR2=0b00000001;      // CMP1 (iDum) High priority
  IPR3=0b00110000;      // USART1 (iDum) High priority
  IPR4=0b00010001;      // TMR5 (Samsung transmitt), TMR1 (iDum) High priority
  CM1CON1=0x01;         // Komparátor na sestupnou hranu
  
  INTCON=0b11100000;    // GIEH, GIEL, IPEN
  
  DelayMs(100);
  
  LastRand+=TMR3;               // Inicializace náhodného čísla využívá toho, že vnitřní LF oscilátor není stejně stabilní, jako krystalový
  srand(LastRand);
  TMR3CLK=0b0001;               // fosc/4
  T3CON=0b00000000;             // TMR3OFF
  
  ZjistiVstupy();
  
  while(1)
  {
    if((ByloPreruseni1)&&(ByloPreruseni2)) 
    {
      ByloPreruseni1=0;
      ByloPreruseni2=0;
      ClrWdt();
      i=DevID;
      if(i!=EECheckSum) ReloadEEPROM();
    }
    
    ZjistiVstupy();
    if((BylaZmenaVstupu)&&(!CasZakmitu))
    {
      i=Vstup;
      BylaZmenaVstupu=0;
      VysliByte(0x01,rksStatus,i);
    }
    
    #if(Build==Release)
    if((Cas>=CasUsnuti)&&(!PrijimamData)&&(!ZpravaPrijata)&&(!TMR5ON)&&(!BylaZmenaVstupu))
    {
      IOCCF=0;
      PIR0bits.IOCIF=0;
      PIE0bits.IOCIE=1;
      Sleeping=1;
      SLEEP();
      NOP();
      NOP();
      Sleeping=0;
      GIE=0;
      if(Cas>CasUsnuti) Cas=CasUsnuti;
      GIE=1;
      PIE0bits.IOCIE=0;
      CLRWDT();
      i=DevID;
      if(EECheckSum!=i) ReloadEEPROM();
      LastRand=(unsigned int)rand();
    }
    #endif
    
    if(ZpravaPrijata)
    {
      ZpravaPrijata=0;
      switch(Zprava.Data.Typ)
      {
        case msgByte:
        {
          if(Zprava.Data.Obsah.ZByte.ByteID==rksPower)
          {
            OnOff=Zprava.Data.Obsah.ZByte.Value;
            VysliAccept();
            break;
          }
          break;
        }
        case msgArray:
        {
          if(Zprava.Data.Obsah.ZArray.Data[0]==rksCommand)
          {
            Opt=(TOptions *)&Zprava.Data.Obsah.ZArray.Data[4];
            Swing=(TSwing *)&Zprava.Data.Obsah.ZArray.Data[6];
            i=CreatePaket(SamsungPaket,Zprava.Data.Obsah.ZArray.Data[1],    // Mode
                                       Zprava.Data.Obsah.ZArray.Data[2],    // Temperature
                                       Zprava.Data.Obsah.ZArray.Data[3],    // Fan
                                       *Opt,                                // Options
                                       *Swing,                              // Swing
                                       Zprava.Data.Obsah.ZArray.Data[7],    // Zone
                                       Zprava.Data.Obsah.ZArray.Data[8]);   // Direction
            VysliAccept();
            TransmittPacket(SamsungPaket,i);
            break;
          }
          break;
        }
        case msgQuestion:
        {
          if(Zprava.Data.Obsah.ZQuestion.QuestionType==quStatus)
          {
            Vysilani.Data.Typ=msgAnswer;
            Vysilani.Data.Komu=Zprava.Data.Odkud;
            Vysilani.Data.Odkud=DevID;
            Vysilani.Data.Delka=8;
            Vysilani.Data.UserID=Zprava.Data.UserID;
            Vysilani.Data.Obsah.ZAnswerByte.Action=quStatus;
            Vysilani.Data.Obsah.ZAnswerByte.Value=Vstup;
            VysliPole();
            break;
          }
          break;
        }
        case msgExtended: // Globální příkazy
        {
          if(Zprava.Data.Obsah.Extended.EID==extGetIDTime)
          {
            SendIDTime(Zprava.Data.Odkud);
            break;
          }
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

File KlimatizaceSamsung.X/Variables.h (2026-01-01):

/*
 * Definice a proměnné pro řízení klimatizace Samsung
 */

#ifndef VARIABLES_H
#define	VARIABLES_H

#ifdef	__cplusplus
extern "C"
{
  #endif

  #include "../../DevTypes.h"

  #define MaxBufLen       64
  #define DevType         dtKlimatizaceSamsung

  #include "../../Zpravy.h"

  #define Cas1ms              (0xFFFF-CrystalFreq/4000+1) // (0x10000-CrystalFreq/4000) dává hlášku Arithmetic overflow in constant expression
  #define CasScanu            (Cas1ms/2+0x8000)

  #define Rx              PORTCbits.RC7
  #define Tx              LATBbits.LATB2
  #define TrisTx          TRISBbits.TRISB2
  #define IRControl       LATAbits.LATA2
  #define OnOff           LATAbits.LATA3
  #define Active          PORTCbits.RC0
  #define AccessIO        PORTBbits.RB7
  
  
  #define iDumTxIO()      { RB2PPS = 0x00; }               // LATB2 -> RB2
  #define iDumTxUART()    { RB2PPS = 0x09; }               // TX1   -> RB2
  
  // Pozice konfigurace v paměti EEPROM
  #define EEPROM_DevID            0u
  #define EEPROM_CasZakmitu       EEPROM_DevID+1
  #define EEPROM_Popis            8u
  
  // Příkazy pro modul řízení klimatizace Samsung
  #define rksPower                0x01  // Sepnutí vypínače
  #define rksStatus               0x02  // Změna stavu
  #define rksCommand              0x03  // Příkaz (emulace DO)
  
  // Proměnné pro systém iDům
  TZprava Docasna,Zprava,Vysilani,TempZprava,ZalohaZpravy;
  __near unsigned char Cas,EECheckSum;
  __near unsigned char PoziceZpravy,PrijatyZnak,DevID,Configuring,WaitingTime;
  __near bit PrijimamData,ZpracovavamData,ZpravaPrijata,VysilaniSelhalo,Vysilam;
  __near bit ZpravaVyslana,Sleeping,ByloPreruseni1,ByloPreruseni2;
  unsigned char RandID[4];
  __persistent unsigned int LastRand;   // Náhodné číslo
  __persistent unsigned int IDV_OK,IDV_Sent,IDV_Fail,IDV_Error,IDV_Conflict,IDV_Reset;
  
  // Proměnné specifické pro hardware
  unsigned int CasDelay;              // Čekání pro čekací smyčku
  unsigned char CasZakmitu;           // Čas zákmitů
  unsigned char Vstup;                // Stav vstupů
  unsigned char StaryVstup;           // Původní stav vstupů
    
  bit BylaZmenaVstupu;                // Došlo ke změně vstupu
  
  void ReloadEEPROM(void);

  #ifdef	__cplusplus
}
#endif

#endif	/* VARIABLES_H */
